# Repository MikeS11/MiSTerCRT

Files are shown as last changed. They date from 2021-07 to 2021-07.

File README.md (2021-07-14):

[][contributors-url]
[][forks-url]
[][stars-url]
[][issues-url]
[][license-url]
[][Twitter-url]

<!-- PROJECT LOGO -->
<br />
<p align="center">
  <a href="https://github.com/MikeS11/MiSTerCRT">
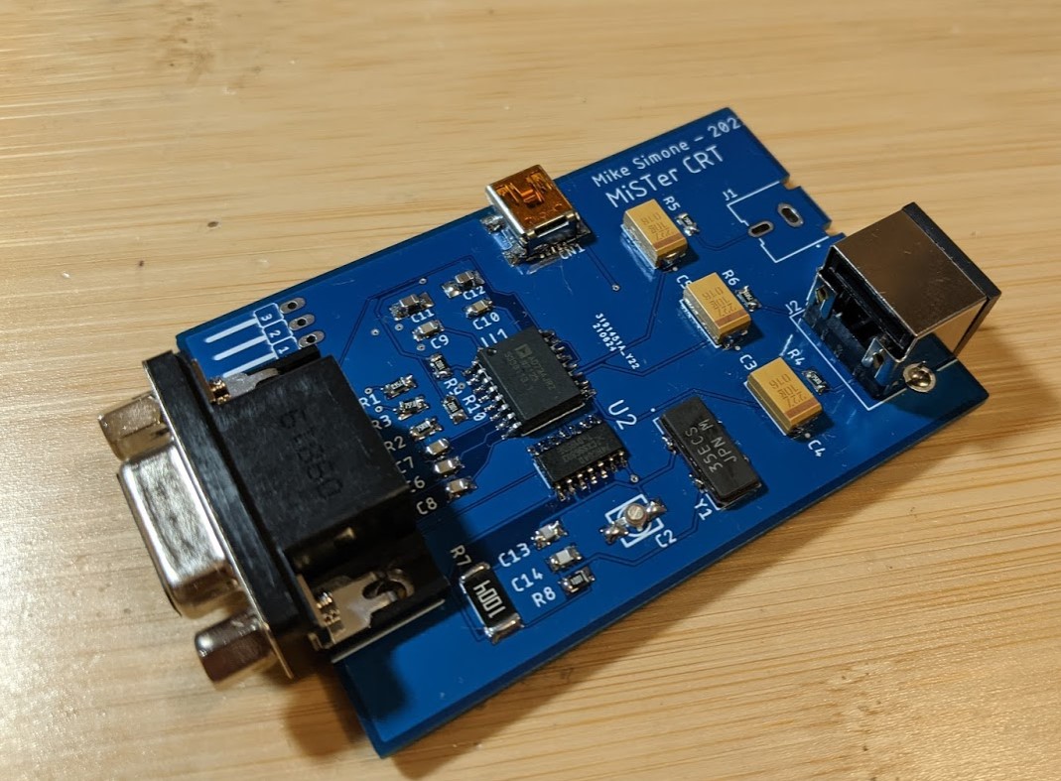
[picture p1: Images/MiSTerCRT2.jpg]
    
  </a>
  <a href="https://github.com/MikeS11/MiSTerCRT">
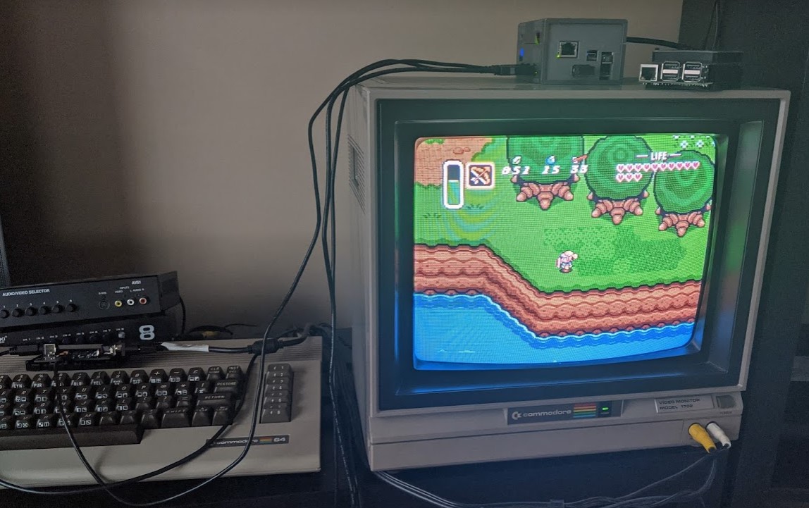
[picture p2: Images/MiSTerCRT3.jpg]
   <br> 
  </a>
  <h3 align="center">MiSTerCRT - S-Video / Composite Adapter</h3>

  <p align="center">

<!-- TABLE OF CONTENTS -->
## Table of Contents

* [About the Project](#about-the-project)
  * [Built With](#Build-Requirements)
* [Getting Started](#getting-started)
  * [Prerequisites](#prerequisites)
* [License](#license)
* [Contact](#contact)
* [Acknowledgements](#acknowledgements)

<!-- ABOUT THE PROJECT -->
## About The Project
Wanted to add a open source option for getting S-Video / Composite out of a MiSTer and add some flexiblity to tune the NTSC crystal through a trim capacitor.
  
#Note - I still need to test out the composite port

### Getting Started
You can use either power from the 5V VGA port (Through the IO Board jumper) or directly through USB. Make sure you only use one of those options.

Also I've added a trim capacitor to tune the NTSC crystal if required. (I've noticed some cores tend to have some additional flicker that can be tuned to improve the image through a trim capacitor.
  
For settings in the ini file, make sure vga_scaler is off and you flip sync on green on the IO board to off as well. 

### Build Requirements:
  
|QUANTITY |	PART NUMBER	|	DESCRIPTION	| UNIT PRICE (Canadian)	|
|  --- | --- | --- | --- |
| 1		 | CP-2240-ND		|	CONN RCPT FMALE MINI DIN 4P SLDR	|  2.38000		|
| 1		 | CP-1421-ND		|	CONN RCA JACK MONO 3.2MM R/A		  |  2.16000		|
| 1		 | XC584CT-ND		|	CRYSTAL 3.579545MHZ 17PF SMD		  |  2.47000		|
| 1		 | AD724JRZ-ND		|	IC ENCODER RGB TO NTSC 16-SOIC		|  26.77000	|
|1	|	609-10033526-N3222MLFCT-ND	|MINI USB B TYPE RECEPT	|		1.09000		|
|1	|	1727-3776-ND	|		IC INVERTER 6CH 6-INP 14SO	|	0.51400	|
|1 | 	311-1.00KCRCT-ND| 		RES SMD 1K OHM 1% 1/8W 0805 | 0.02340			| 
| 6	|	RMCF0805FT75R0CT-ND		|RES 75 OHM 1% 1/8W 0805		|	0.01540		|  
|2 | 311-10.0KCRCT-ND| 	RES SMD 10K OHM 1% 1/8W 0805 | 0.02340	|
|1	|	13-RC2512FK-071MLCT-ND	|	RES SMD 1M OHM 1% 1W 2512	|	0.47300		|
|5 | 399-1171-1-ND	| CAP CER 0.1UF 50V X7R 0805 | 0.11020	|
|2 | 399-15693-1-ND| 		CAP CER 10UF 10V X7R 0805 | 0.85900		|  
|1	|	311-4241-1-ND		|	CAP CER 62PF 50V NPO 0805	(60PF is recommended if you can find it)|0.14200		|
|1	|	720-VJ0805A470GXJPW1BCCT-ND	|CAP CER 47PF 16V C0G/NP0 0805	|	0.22600		| 
|3	|	399-9744-1-ND		|	CAP TANT 220UF 20% 10V 2917	|	1.90000		|  
| 1		 | SG9212-ND		|	  Optional - CAP TRIMMER 5-25PF 25V SMD (Recommended to fine tune NTSC signal) | 1.40000	|
| 1		 | XM4L-1542-132  | CONN D-SUB HD RCPT 15P R/A SLDR  | 4.47000 | 

If you need jumpers, S9001-ND, CONN JUMPER SHORTING GOLD FLASH

  <a href="https://github.com/MikeS11/MiSTerCRT">
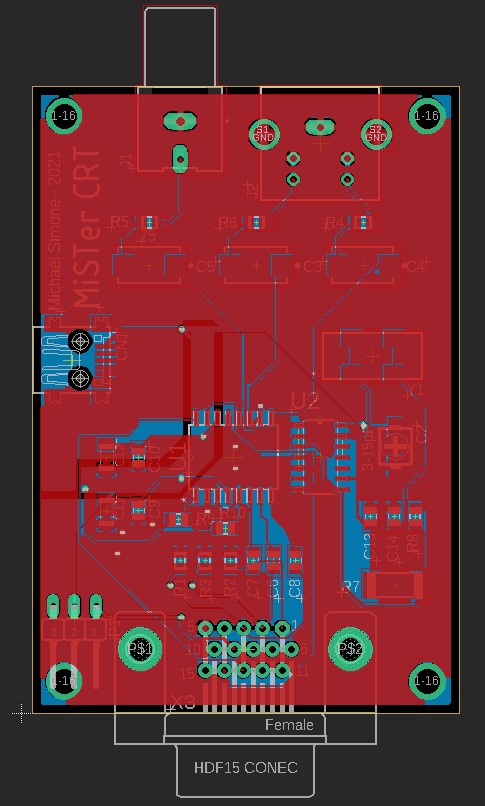
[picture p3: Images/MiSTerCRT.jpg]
   <br> 
  </a>

<p align="center">
</p>
<p align="center">
</p>
<!-- CONTRIBUTING -->
## Contributing

Contributions are what make the open source community such an amazing place to be learn, inspire, and create. Any contributions you make are **greatly appreciated**.

1. Fork the Project
2. Create your Feature Branch (`git checkout -b feature/AmazingFeature`)
3. Commit your Changes (`git commit -m 'Add some AmazingFeature'`)
4. Push to the Branch (`git push origin feature/AmazingFeature`)
5. Open a Pull Request

<!-- LICENSE -->
## License

Distributed under the MIT License. See `LICENSE` for more information.

<!-- CONTACT -->
## Contact

Mike Simone - [@mikesimone3](https://twitter.com/mikesimone3) 

Project Link: [https://github.com/MikeS11/MiSTerCRT](https://github.com/MikeS11/MiSTerCRT)

<!-- ACKNOWLEDGEMENTS -->
## Acknowledgements

<!-- MARKDOWN LINKS & IMAGES -->
<!-- https://www.markdownguide.org/basic-syntax/#reference-style-links -->
[contributors-shield]: https://img.shields.io/github/contributors/MikeS11/MiSTerCRT.svg?style=flat-square
[contributors-url]: https://github.com/MikeS11/MiSTerCRT/graphs/contributors
[forks-shield]: https://img.shields.io/github/forks/MikeS11/MiSTerCRT.svg?style=flat-square
[forks-url]: https://github.com/MikeS11/MiSTerCRT/network/members
[stars-shield]: https://img.shields.io/github/stars/MikeS11/MiSTerCRT.svg?style=flat-square
[stars-url]: https://github.com/MikeS11/MiSTerCRT/stargazers
[issues-shield]: https://img.shields.io/github/issues/MikeS11/MiSTerCRT.svg?style=flat-square
[issues-url]: https://github.com/MikeS11/MiSTerCRT/issues
[license-shield]: https://img.shields.io/github/license/MikeS11/MiSTerCRT.svg?style=flat-square
[license-url]: https://github.com/MikeS11/MiSTerCRT/blob/master/LICENSE.txt
[twitter-shield]: https://img.shields.io/badge/-Twitter-black.svg?style=flat-square&logo=Twitter&colorB=555
[twitter-url]: https://Twitter.com/mikesimone3
[product-screenshot]: images/screenshot.png

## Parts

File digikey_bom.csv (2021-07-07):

Index | Quantity | Part Number | Manufacturer Part Number | Description | Customer Reference | Available | Backorder | Unit Price | Extended Price USD
1 | 1 | CP-2240-ND | MD-40SM | CONN RCPT FMALE MINI DIN 4P SLDR |  | 1 | 0 | 1.83000 | 1.83
2 | 1 | CP-1421-ND | RCJ-044 | CONN RCA JACK MONO 3.2MM R/A |  | 0 | 1 | 1.66000 | 1.66
3 | 1 | XC584CT-ND | ECS-35-17-18-TR | CRYSTAL 3.579545MHZ 17PF SMD |  | 1 | 0 | 1.78000 | 1.78
4 | 1 | AD724JRZ-ND | AD724JRZ | IC ENCODER RGB TO NTSC 16-SOIC |  | 1 | 0 | 18.90000 | 18.90
5 | 1 | 609-10033526-N3222MLFCT-ND | 10033526-N3222MLF | MINI USB B TYPE RECEPT |  | 1 | 0 | 0.82000 | 0.82
6 | 1 | 1727-3776-ND | 74HC04D,652 | IC INVERTER 6CH 6-INP 14SO |  | 1 | 0 | 0.45000 | 0.45
7 | 1 | 311-1.00KCRCT-ND | RC0805FR-071KL | RES SMD 1K OHM 1% 1/8W 0805 |  | 1 | 0 | 0.10000 | 0.10
8 | 6 | RMCF0805FT75R0CT-ND | RMCF0805FT75R0 | RES 75 OHM 1% 1/8W 0805 |  | 6 | 0 | 0.10000 | 0.60
9 | 2 | 311-10.0KCRCT-ND | RC0805FR-0710KL | RES SMD 10K OHM 1% 1/8W 0805 |  | 2 | 0 | 0.10000 | 0.20
10 | 1 | 13-RC2512FK-071MLCT-ND | RC2512FK-071ML | RES SMD 1M OHM 1% 1W 2512 |  | 0 | 1 | 0.47000 | 0.47
11 | 5 | 399-1171-1-ND | C0805C104J5RACTU | CAP CER 0.1UF 50V X7R 0805 |  | 1 | 4 | 0.21000 | 1.05
12 | 2 | 399-15694-1-ND | C0805X106J8RAC7800 | CAP CER 10UF 10V X7R 0805 |  | 2 | 0 | 0.93000 | 1.86
13 | 1 | 311-4241-1-ND | CC0805JRNPO9BN620 | CAP CER 62PF 50V NPO 0805 |  | 1 | 0 | 0.15000 | 0.15
14 | 1 | 720-VJ0805A470GXJPW1BCCT-ND | VJ0805A470GXJPW1BC | CAP CER 47PF 16V C0G/NP0 0805 |  | 1 | 0 | 0.25000 | 0.25
15 | 3 | 399-9744-1-ND | T491D227M010AT | CAP TANT 220UF 20% 10V 2917 |  | 3 | 0 | 1.43000 | 4.29
16 | 1 | SG9212-ND | GKH25000 | CAP TRIMMER 5-25PF 25V SMD |  | 1 | 0 | 1.05000 | 1.05
17 | 1 | Z13226-ND | XM4L-1542-132 | CONN D-SUB HD RCPT 15P R/A SLDR |  | 0 | 1 | 2.64000 | 2.64
18 | 1 | S9001-ND | SPC02SYAN | CONN JUMPER SHORTING GOLD FLASH |  | 1 | 0 | 0.10000 | 0.10

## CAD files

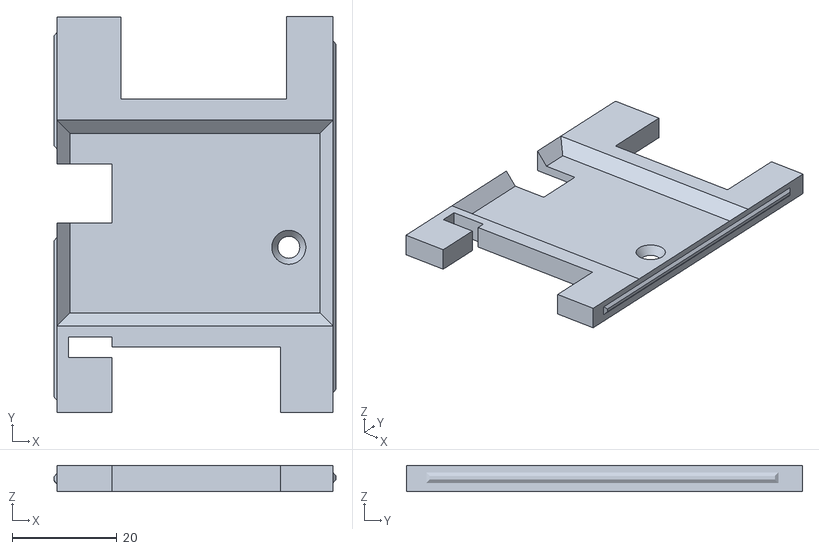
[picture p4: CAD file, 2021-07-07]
Case/MiSTerCRT_Top.stl
53.8 x 75.6 x 5.00

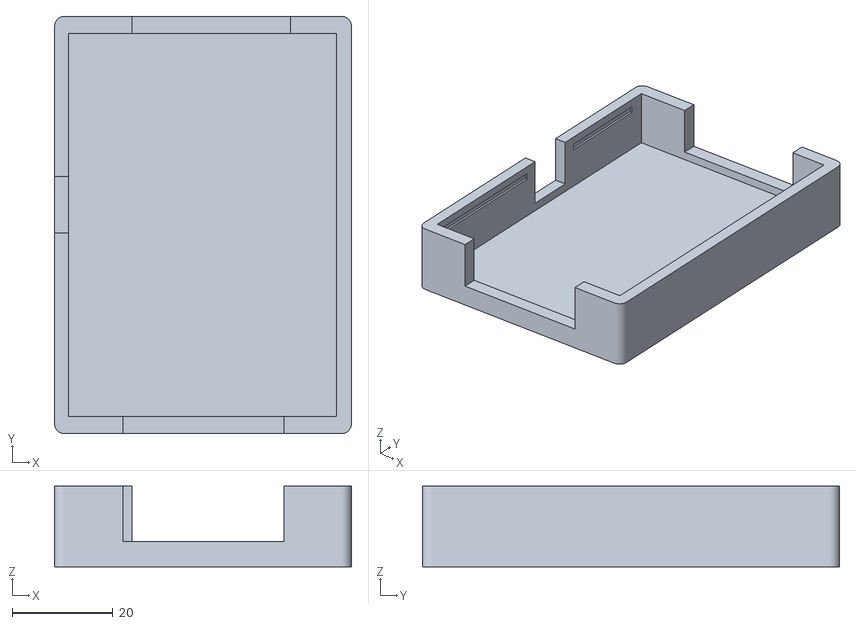
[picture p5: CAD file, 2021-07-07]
Case/MiSTerCRT_Bottom.stl
59.0 x 82.9 x 16.0

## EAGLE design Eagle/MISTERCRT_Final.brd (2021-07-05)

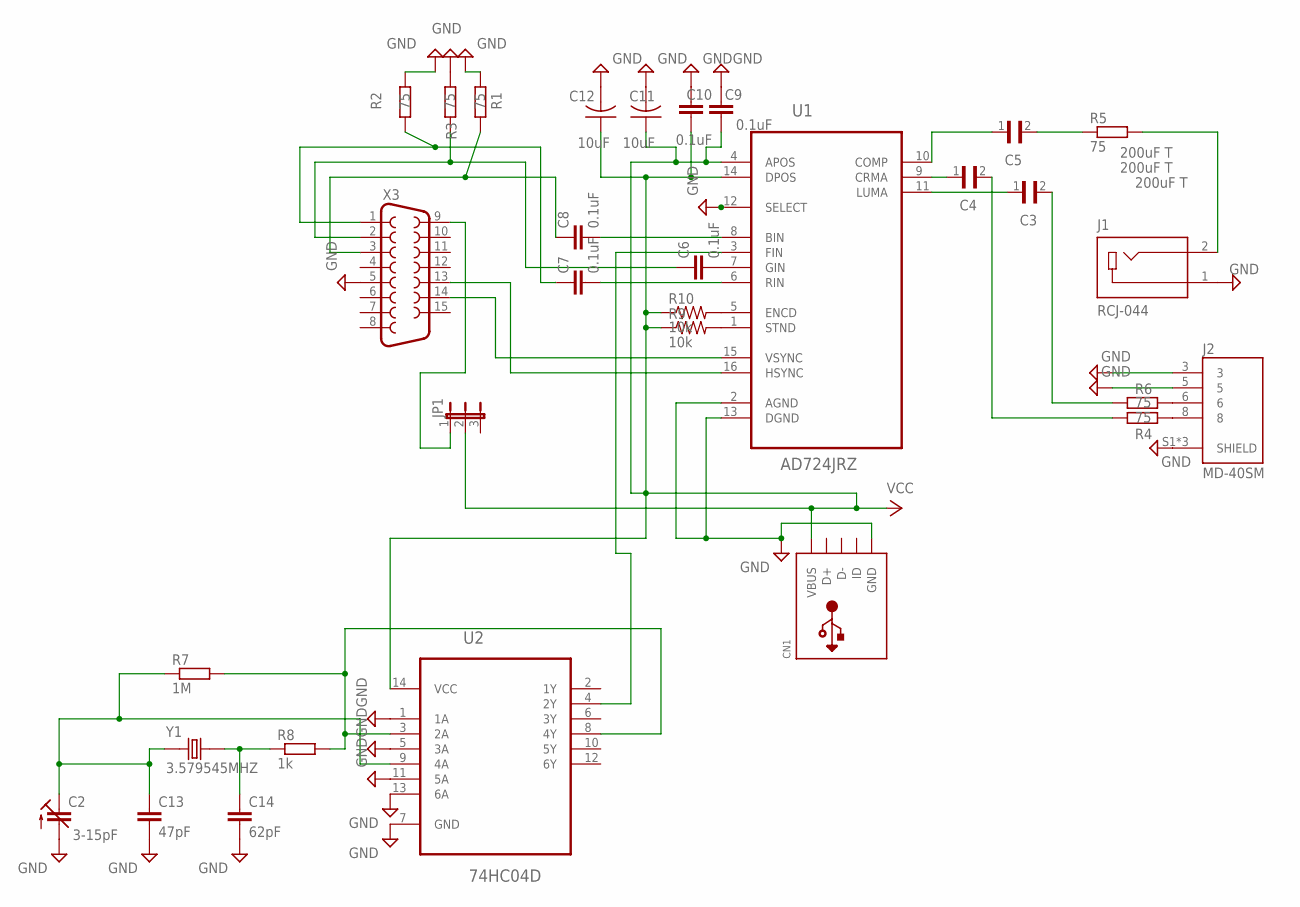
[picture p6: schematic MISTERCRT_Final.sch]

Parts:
C2: 3-15pF; CTRIM3018_11
C3, C4, C5: 200uF T; CAPMP7343X430N
C6, C7, C8, C9, C10: 0.1uF; C0805
C11, C12: 10uF; C1206K
C13: 47pF; C0805
C14: 62pF; C0805
CN1: USBMINIB; USB-MINIB
J1: RCJ-044; CUI_RCJ-044
J2: MD-40SM; CUI_MD-40SM
JP1: JP2W
R1, R2, R3, R4, R5, R6: 75; M0805
R7: 1M; R2512
R8: 1k; R0805
R9, R10: 10k; R0805
U1: AD724JRZ; SOIC127P1032X265-16N
U2: 74HC04D; SOIC127P600X175-14N
X3: F15HDH; HDF15H
Y1: 3.579545MHZ; XTAL_ECS-35-17-18-TR

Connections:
GND: C2.- (A), C9.2, C10.2, C11.2, C12.2, C13.2, C14.2, CN1.GND, J1.1, J2.3, J2.5, J2.S1 (SHIELD), J2.S2 (SHIELD), J2.S3 (SHIELD), R1.2, R2.2, R3.2, U1.2 (AGND), U1.12 (SELECT), U1.13 (DGND), U2.1 (1A), U2.5 (3A), U2.7 (GND), U2.11 (5A), U2.13 (6A), X3.5
unnamed: C2.+ (E), C13.1, R7.1, U2.9 (4A), Y1.1, Y1.4 (1)
unnamed: R10.2, U1.5 (ENCD)
unnamed: U1.3 (FIN), U2.4 (2Y)
unnamed: C7.1, R2.1, X3.1
unnamed: C6.1, R3.1, X3.2
unnamed: C8.1, R1.1, X3.3
unnamed: U1.16 (HSYNC), X3.13
unnamed: U1.15 (VSYNC), X3.14
unnamed: J2.6, R6.2
unnamed: J2.8, R4.2
unnamed: C3.2, R6.1
unnamed: C3.1, U1.11 (LUMA)
unnamed: C4.2, R4.1
unnamed: C4.1, U1.9 (CRMA)
unnamed: C5.1, U1.10 (COMP)
unnamed: C5.2, R5.1
unnamed: J1.2, R5.2
unnamed: JP1.1, X3.9
unnamed: C6.2, U1.7 (GIN)
unnamed: C7.2, U1.6 (RIN)
unnamed: C8.2, U1.8 (BIN)
unnamed: C14.1, R8.1, Y1.2, Y1.3 (2)
unnamed: R7.2, R8.2, U2.3 (2A), U2.8 (4Y)
unnamed: R9.2, U1.1 (STND)
VCC: C9.1, C10.1, C11.1, C12.1, CN1.VBUS, JP1.2, R9.1, R10.1, U1.4 (APOS), U1.14 (DPOS), U2.14 (VCC)

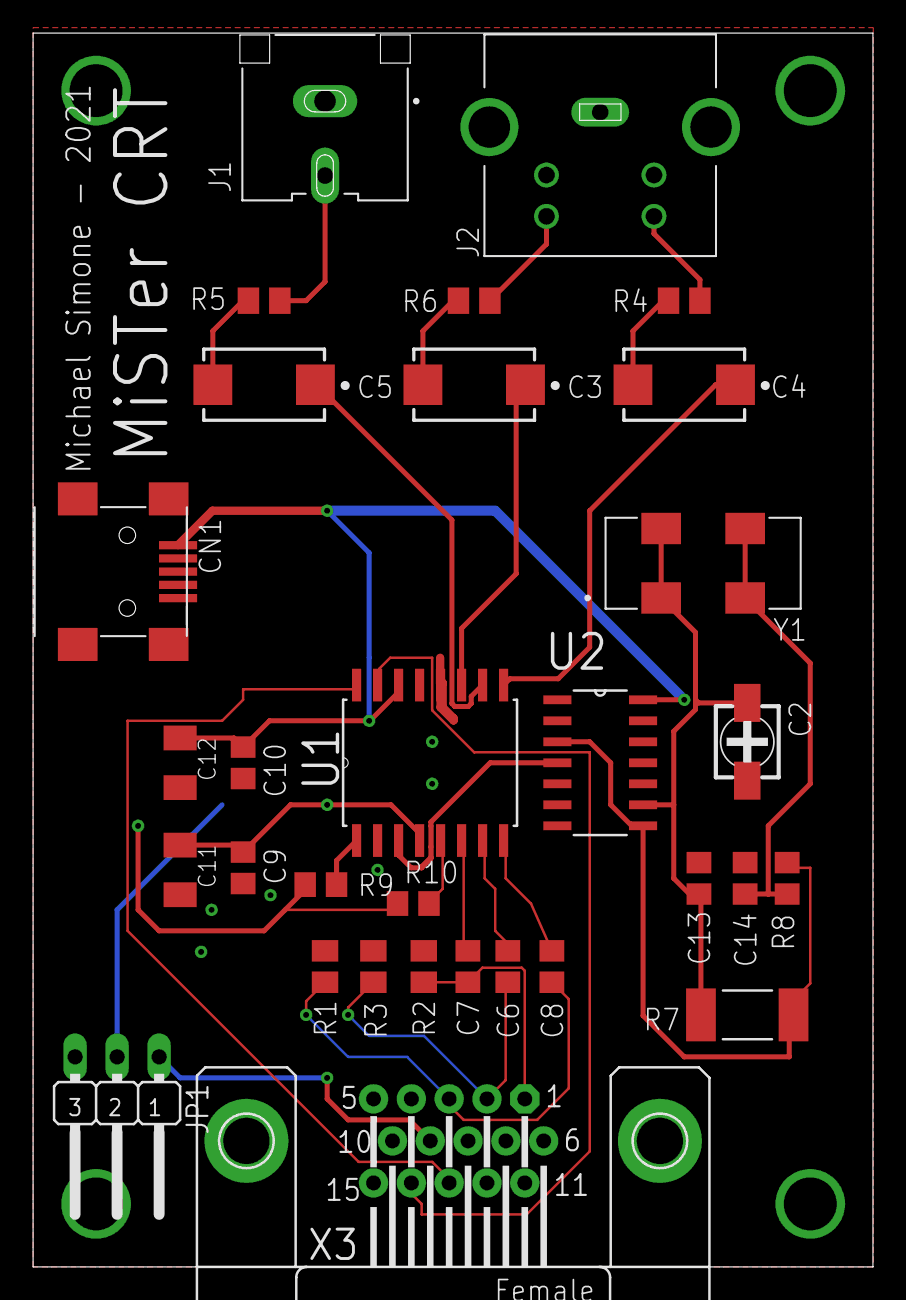
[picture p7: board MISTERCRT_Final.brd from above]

Board: 2 copper layers, 50.8 x 74.6 mm, 31 parts (0 on the bottom side), 26 nets.

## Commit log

2021-07-05 MiSTerCRT - RGB to S-Video / Composite Adapter
    MiSTerCRT - RGB to S-Video / Composite Adapter
    [MISTERCRT_Final.brd, MISTERCRT_Final.sch]
2021-07-06 Add Digikey BOM
    Quick Note: A few items are out of stock and one is out of production, but users could just find a suitable replacement with the tools on Digikey easily enough. Figured I'd start with your list though.
    [digikey_bom.csv]
2021-07-07 Added Case Model
    Added Case Model
    [MiSTerCRT_Bottom.stl, MiSTerCRT_Top.stl]
